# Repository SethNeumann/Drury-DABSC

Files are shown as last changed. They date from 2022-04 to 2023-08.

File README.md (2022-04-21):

# REPO NAME: Drury-DABSC
## License: Creative Commons Attribution-NonCommercial-ShareAlike

Dennis Drury designed the Dual ABS Controller (DABSC) as a simple solution for ABS.  
  
The Dual ABS Signal Controller provides a simple, no software, solution for the modeler looking for a prototypical Automatic Block Signaling (ABS) system.
This board provides signal control for two blocks of 3 aspect (Green - Yellow - Red) route signaling for two blocks.  
The Dual ABS Signal Controller can be used in either single track (1 segment for each signaled direction) or double track (Rule 251, Current of Traffic)
applications.

This is an excellent product for modular and sectional railroads as well as permanent applications.  We recommend our cpOD (screw terminal option) detector
for detection input. The Dual ABS Signal Controller is NOT MSS compatible.

This board is designed and supported by Dennis Drury, a former Southern Pacific Signal Maintainer and the design has given him good service for 30 years!
See Dennis' clinic from the 2017 PCR Convention on the development of this board on the www.modelrailroadcontrolsystems.com sitte under Simple Signaling 
and accessories

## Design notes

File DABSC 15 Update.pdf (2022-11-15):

# Dual ABS Controller V1.5 Update

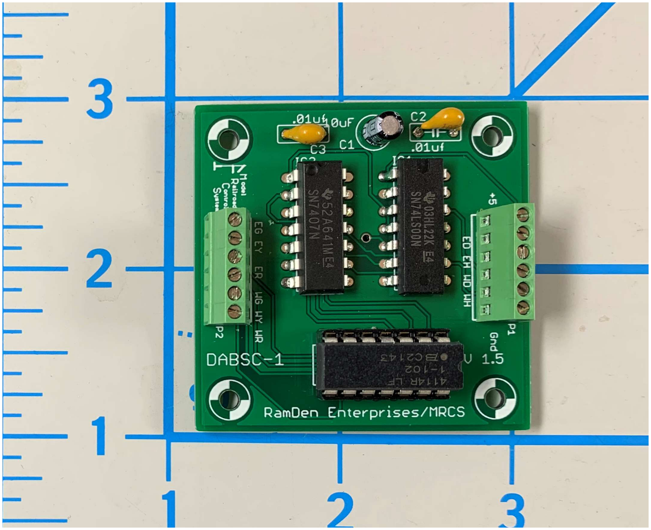
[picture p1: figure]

# Why did we do this update?

## - Changes to current limiting resistors

- Old design was hard to build for stock and test • Resistors values change based on type of signal and users’ color vision
- No easy way to test without soldering resistors in
- Solution: • All resistors on 0.300 grid (same as before) but in 14 pin DIP format • Uses either 14 pin “machined pin” DIP scket or 2 x 7 pin female socket headers
- Allows for use of 7 position DIP resistor networks (if all values the same) or user can insert individual resistors to suit their preferences and change easily.
- Other • Changed 10uF cap to radial (stands up to save space) from axial format • Changed .1 uF ceramic caps to 0.200 spacing to use inventory I had on hand

# Ooops

## - When I panelized the DABSC board, I neglected to check the CAD file for documentation layer, so the output legends were not printed in

the silk screen. This will be corrected in the next build.

Resistor Network*

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
output | input

EG
EY
ER
WG
WY
WR

Resistor network is Bournes 4114R-1-102LF for 1K which is my standard, but these are available in a wide variety of values, or bend 1/4W resistors to 0.300 and insert in socket

- +5 Volts
- ED – East Sensor Distant • EH – East Sensor Home
- WD - West Sensor Distant • WH – West Sensor Home
- GND - Ground
- EG – Eastward Signal Green
- EY – Eastward Signal Yellow
- ER – Eastward Signal Red
- WG - Westward Signal Green
- WY – Westward Signal Yellow
- WR - Westward Signal Red

# Photo

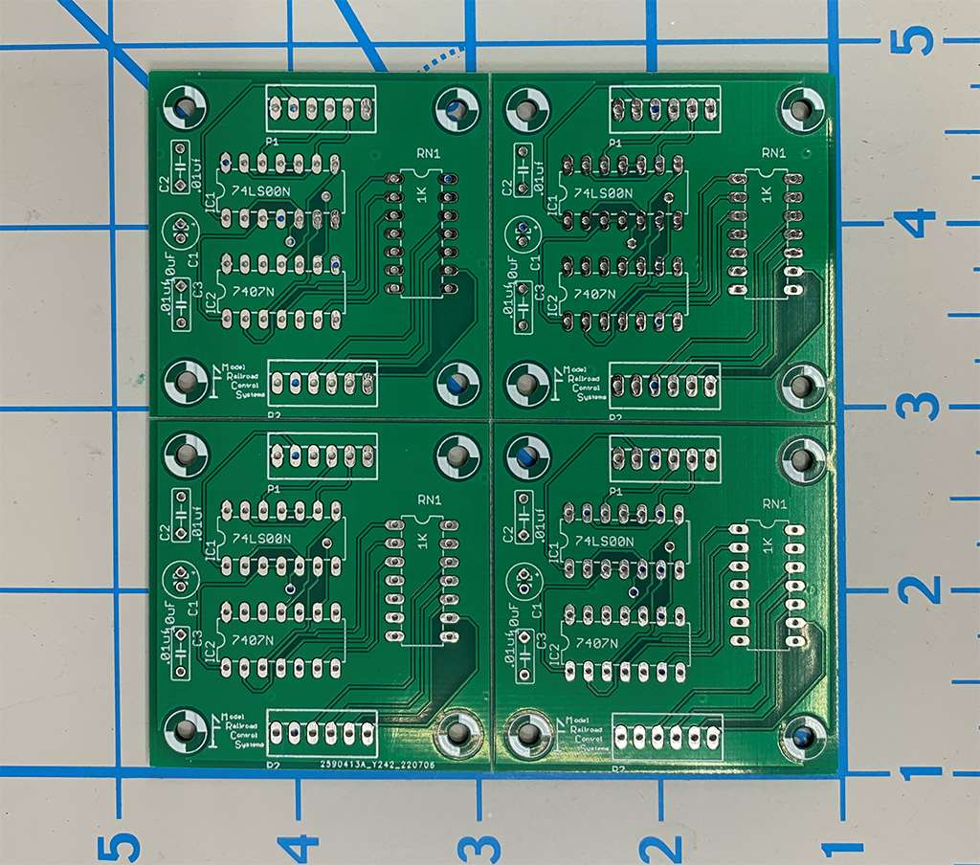
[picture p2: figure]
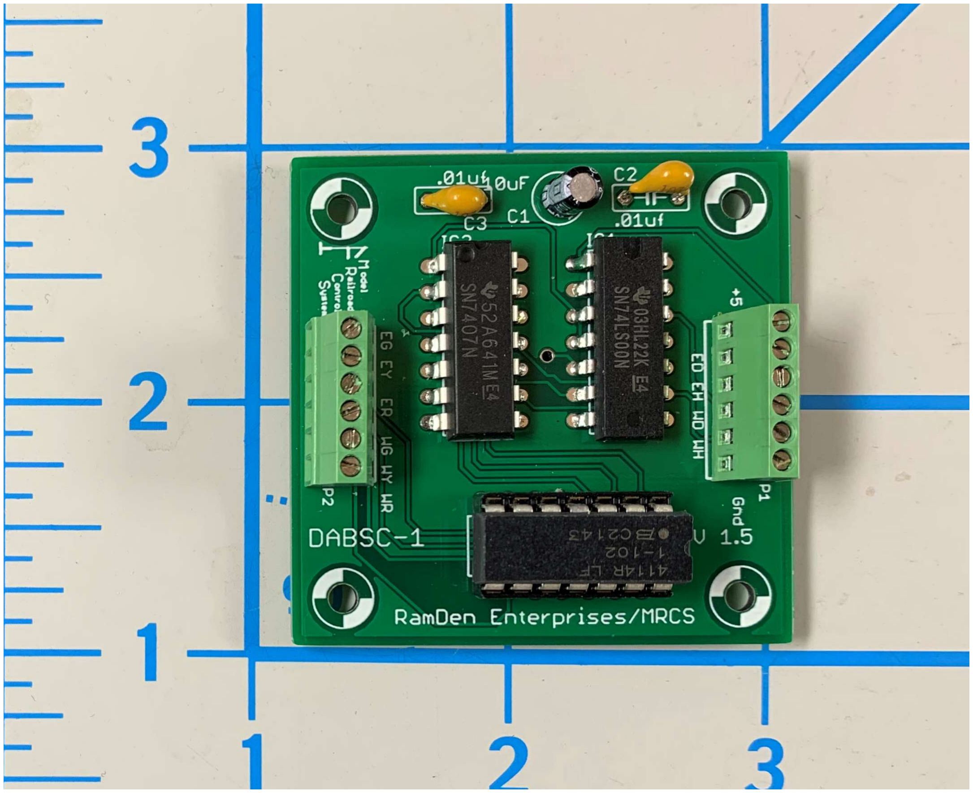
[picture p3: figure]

4 x Panel – no labels | Original Singlet – note labels

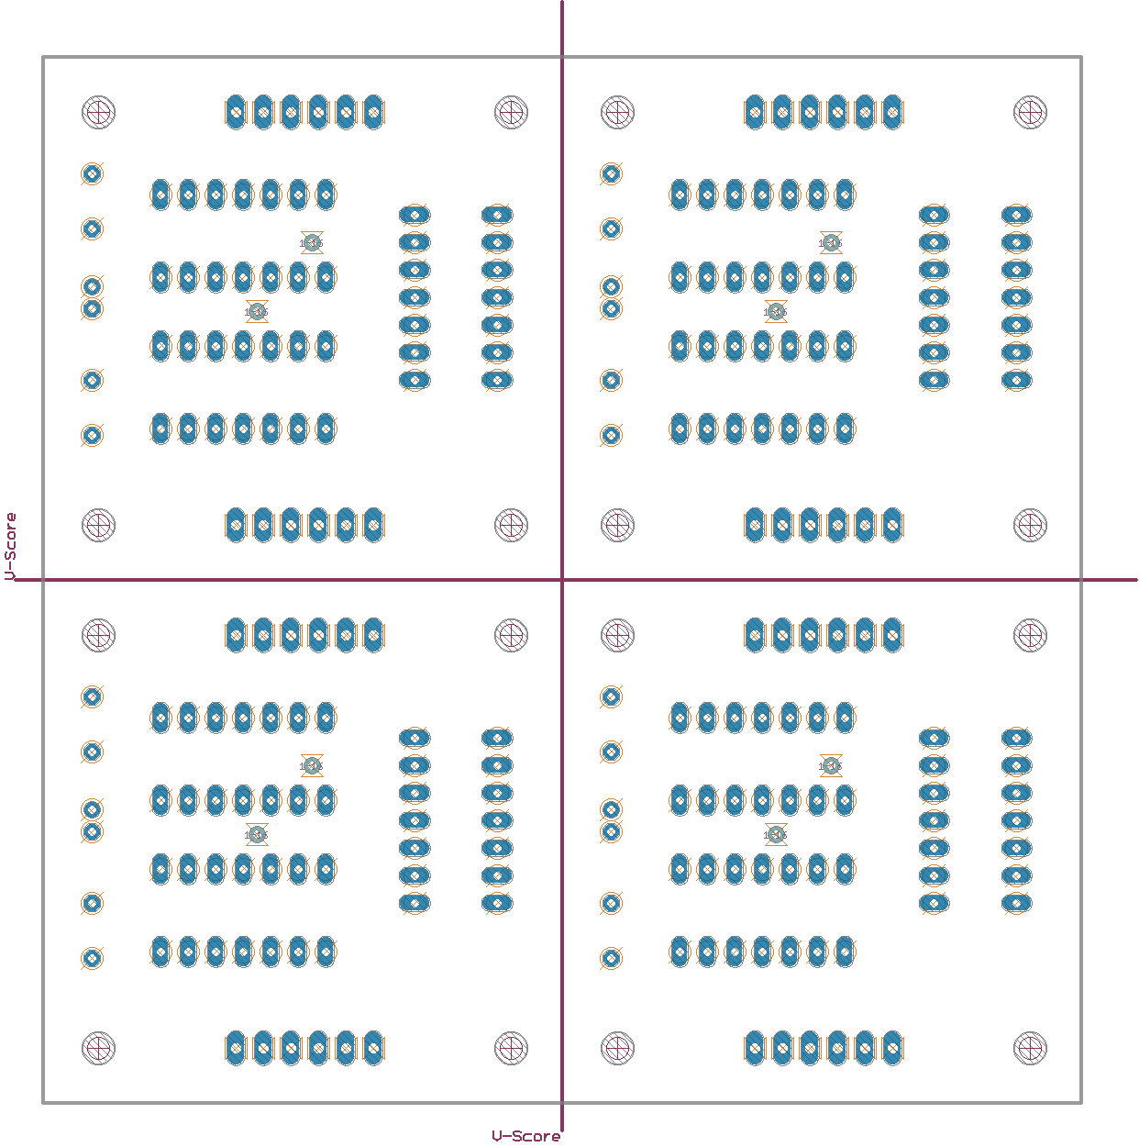
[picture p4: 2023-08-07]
Plocher 20221122/Drury-DABSC_array.bot.brd.png

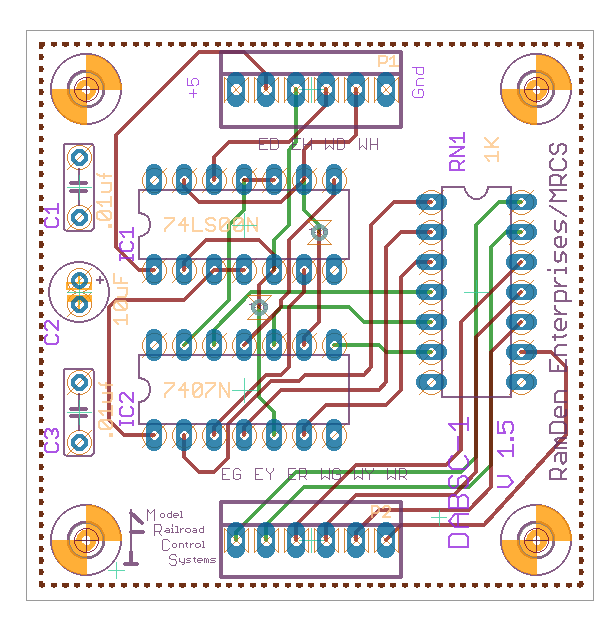
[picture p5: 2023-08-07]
Plocher 20221122/Drury-DABSC.brd.png

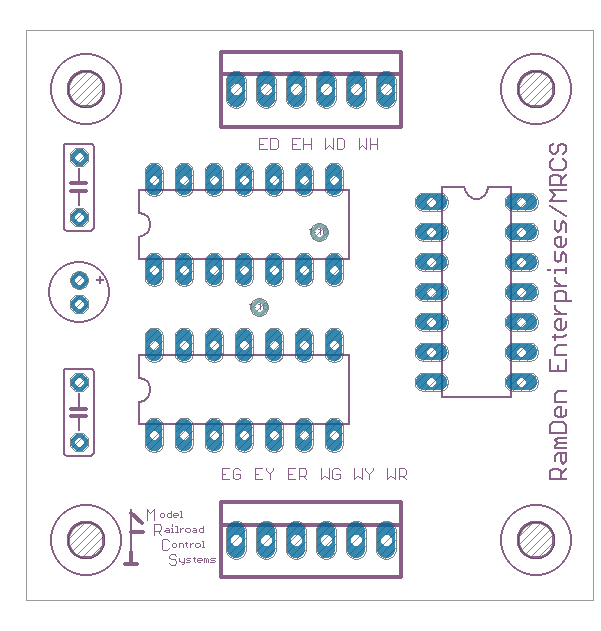
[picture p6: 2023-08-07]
Plocher 20221122/Drury-DABSC.top.brd.png

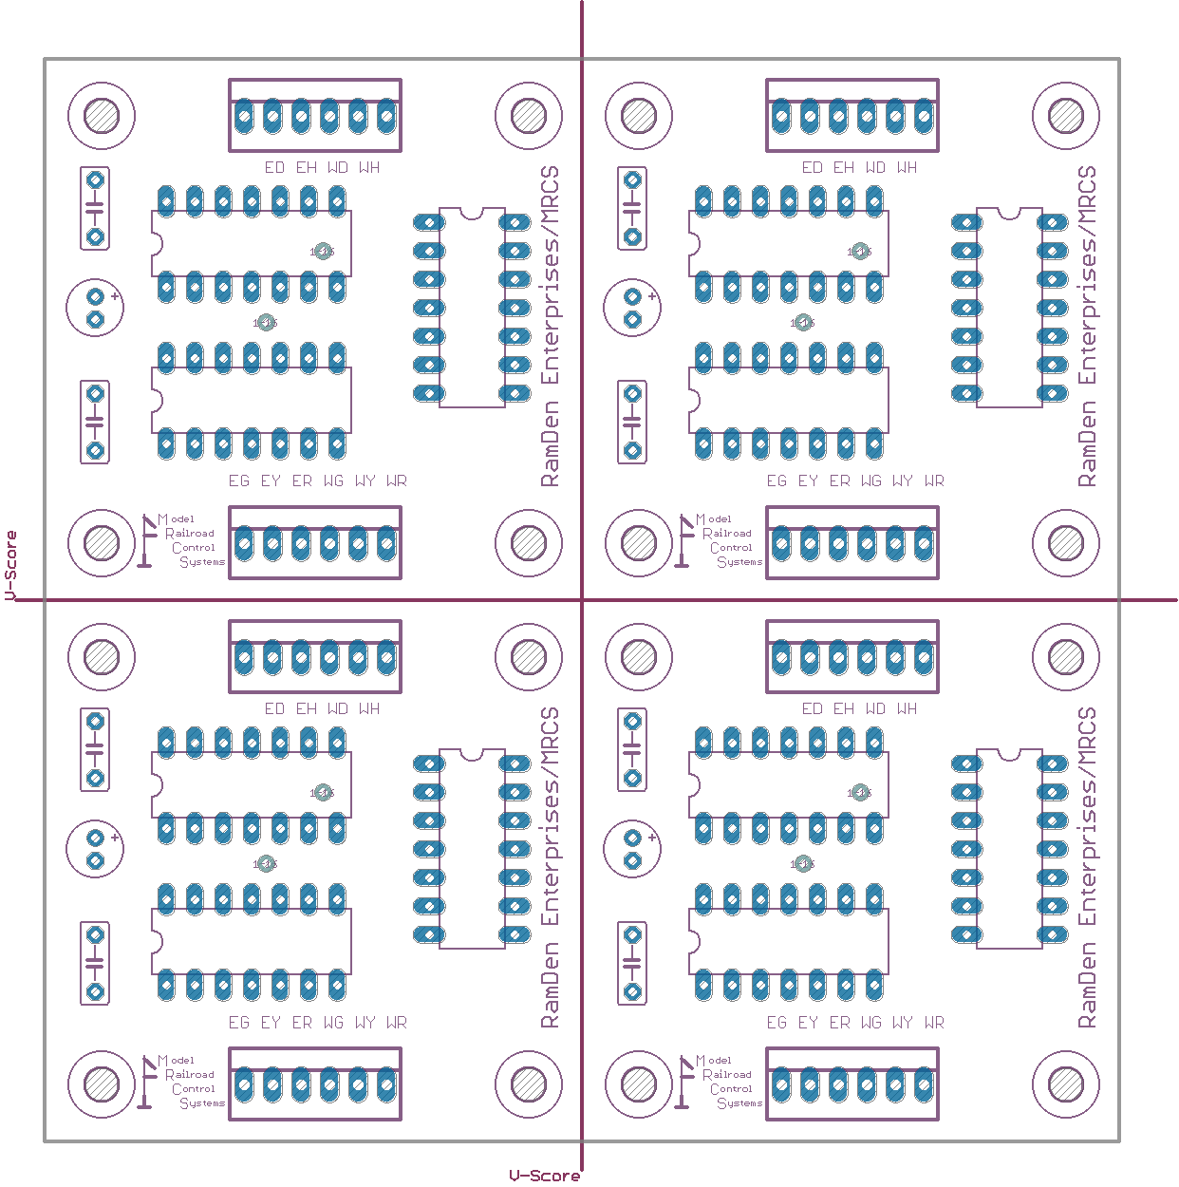
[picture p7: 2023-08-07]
Plocher 20221122/Drury-DABSC_array.top.brd.png

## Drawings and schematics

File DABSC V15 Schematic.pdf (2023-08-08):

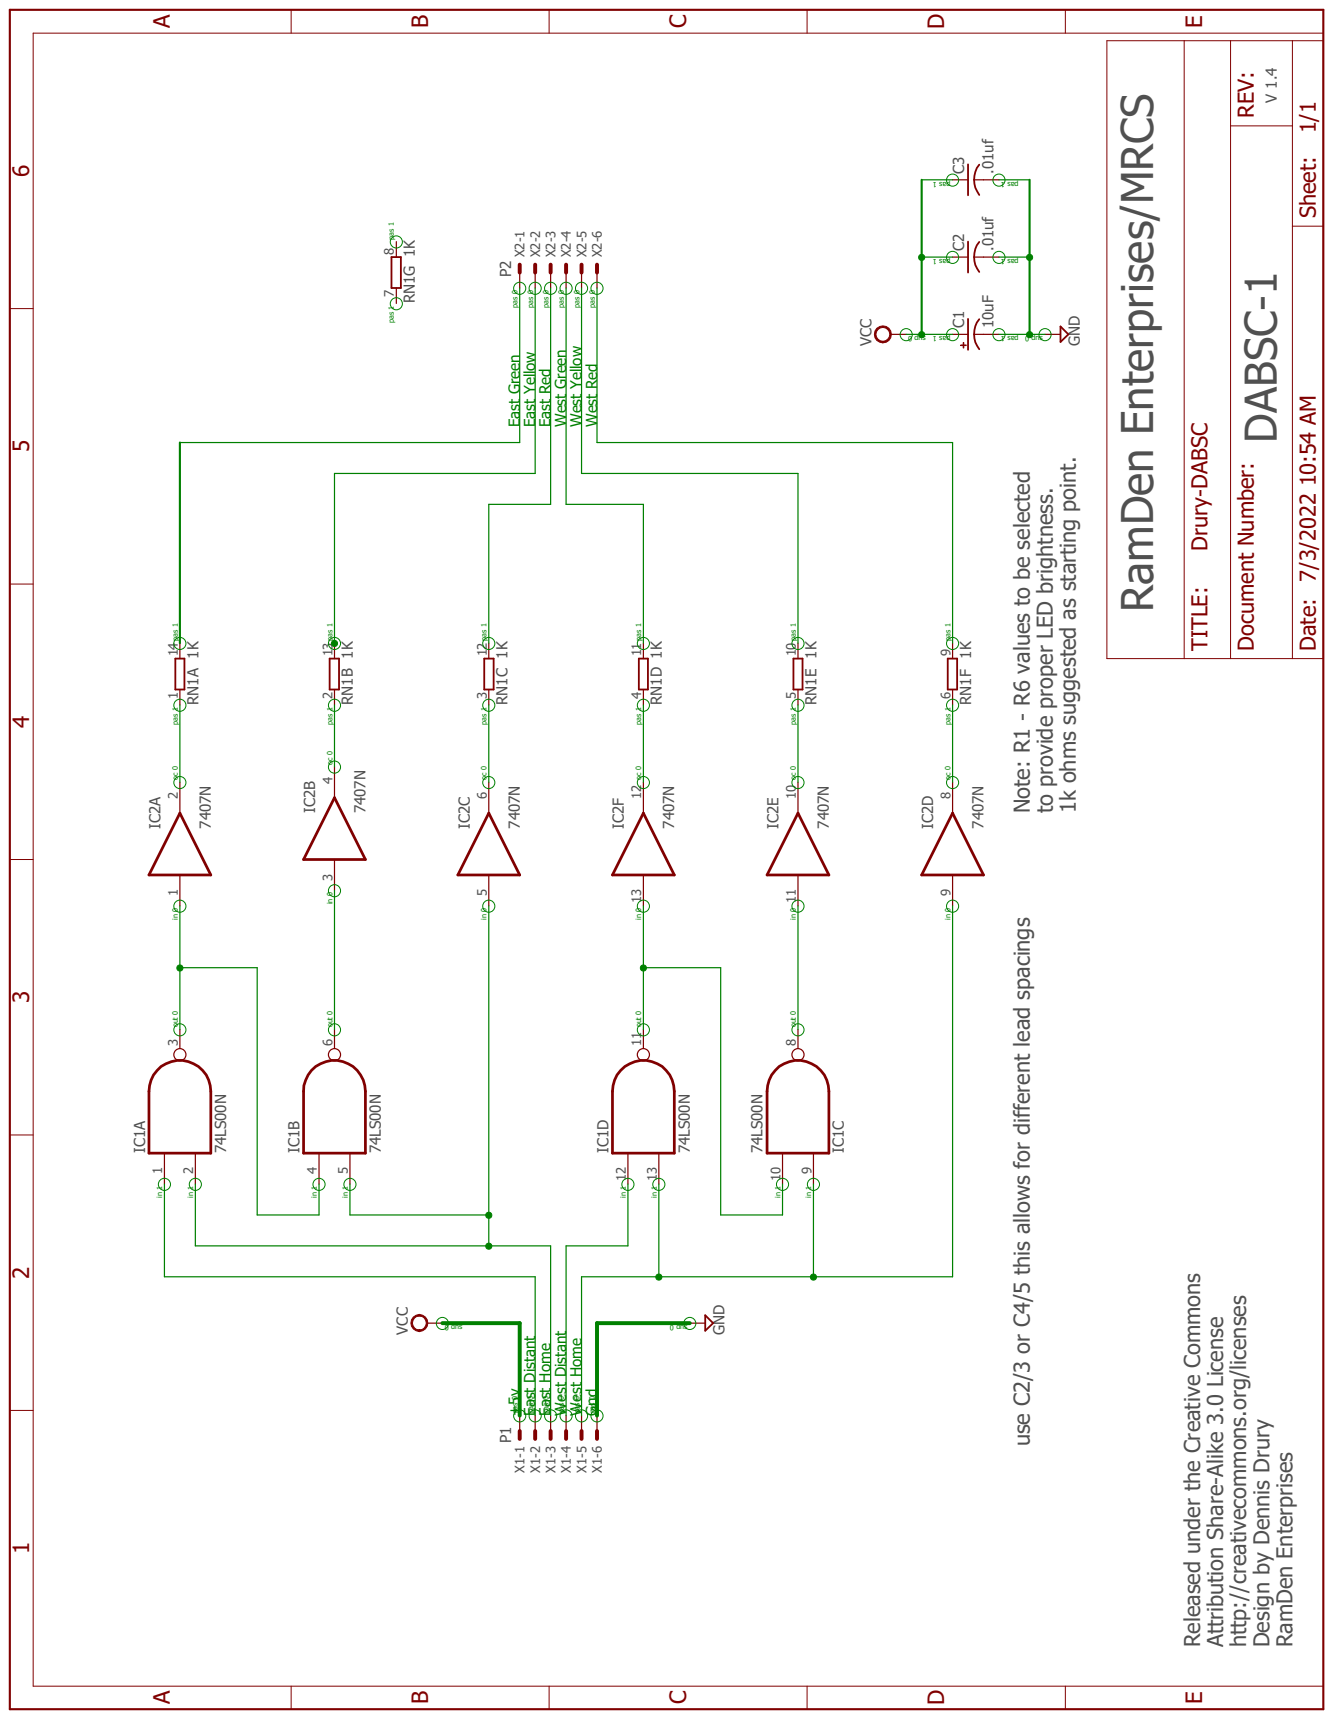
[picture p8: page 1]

RamDen Enterprises/MRCSV 1.4 DABSC-1 Released under the Creative Commons Attribution Share-Alike 3.0 License http://creativecommons.org/licenses Design by Dennis Drury RamDen Enterprises Note: R1 - R6 values to be selected to provide proper LED brightness. 1k ohms suggested as starting point. use C2/3 or C4/5 this allows for different lead spacings 74LS00N 74LS00N 74LS00N 74LS00N 7407N 7407N 7407N 7407N 7407N 7407N GND GND .01uf .01uf VCC VCC10uF P1 P2 1K1K1K1K1K1K 1K 12 3 IC1A 45 6 IC1B 910 8 IC1C 1213 11 IC1D 1 2 IC2A 3 4 IC2B 5 6 IC2C 9 8 IC2D 11 10 IC2E 13 12 IC2F C2 C3 C1 X1-1 X1-2 X1-3 X1-4 X1-5 X1-6 X2-1 X2-2 X2-3 X2-4 X2-5 X2-6 1 14 RN1A 2 13 RN1B 3 12 RN1C 4 11 RN1D 5 10 RN1E 6 9 RN1F 7 8 RN1G ABCDE ABCDE 1 2 3 4 5 6 Date: Sheet: REV: TITLE: Document Number: 7/3/2022 10:54 AM 1/1 Drury-DABSC in 1 in 1 out 0 in 1 in 1 out 0 in 1 in 1 out 0 in 1 in 1 out 0 in 0 oc 0 in 0 oc 0 in 0 oc 0 in 0 oc 0 in 0 oc 0 in 0 oc 0

sup 0 pas 1 pas 1 pas 1 pas 1

sup 0 pas 1 pas 1 pas 0 pas 0 pas 0 pas 0 pas 0 pas 0 pas 0 pas 0 pas 0 pas 0 pas 0 pas 0 pas 1 pas 1 pas 1 pas 1 pas 1 pas 1 pas 1 pas 1 pas 1 pas 1 pas 1 pas 1 pas 1 pas 1 East Distant East Home West Distant West Home East Green East Yellow East Red West Green West Yellow West Red +5v Gnd

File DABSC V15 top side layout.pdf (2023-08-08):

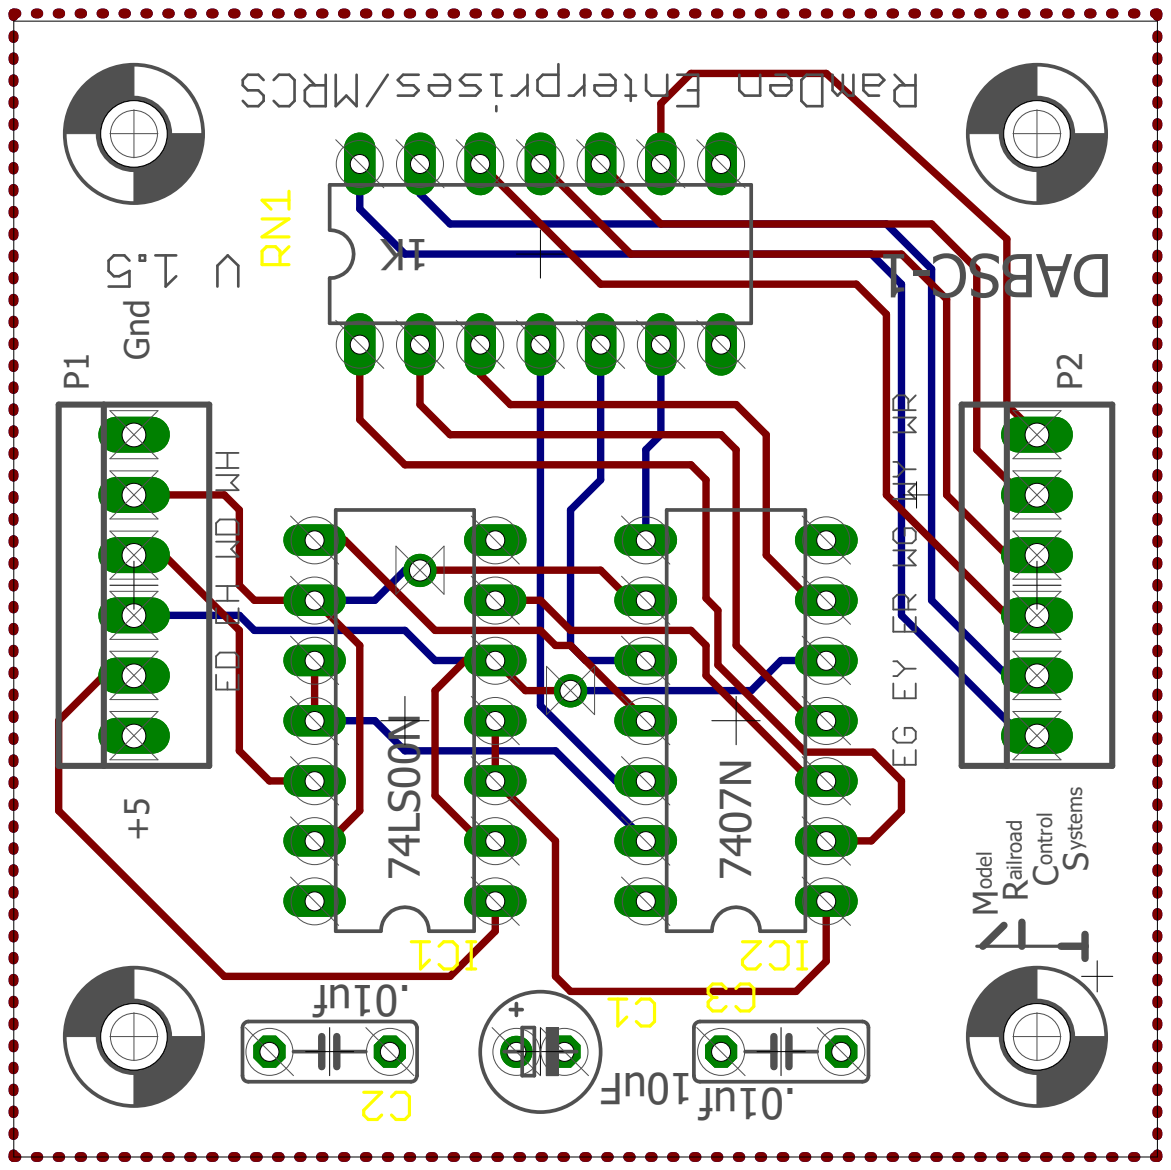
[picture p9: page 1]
DABSC-1 +5 Gnd

MRCSystems ontrol ailroad odel

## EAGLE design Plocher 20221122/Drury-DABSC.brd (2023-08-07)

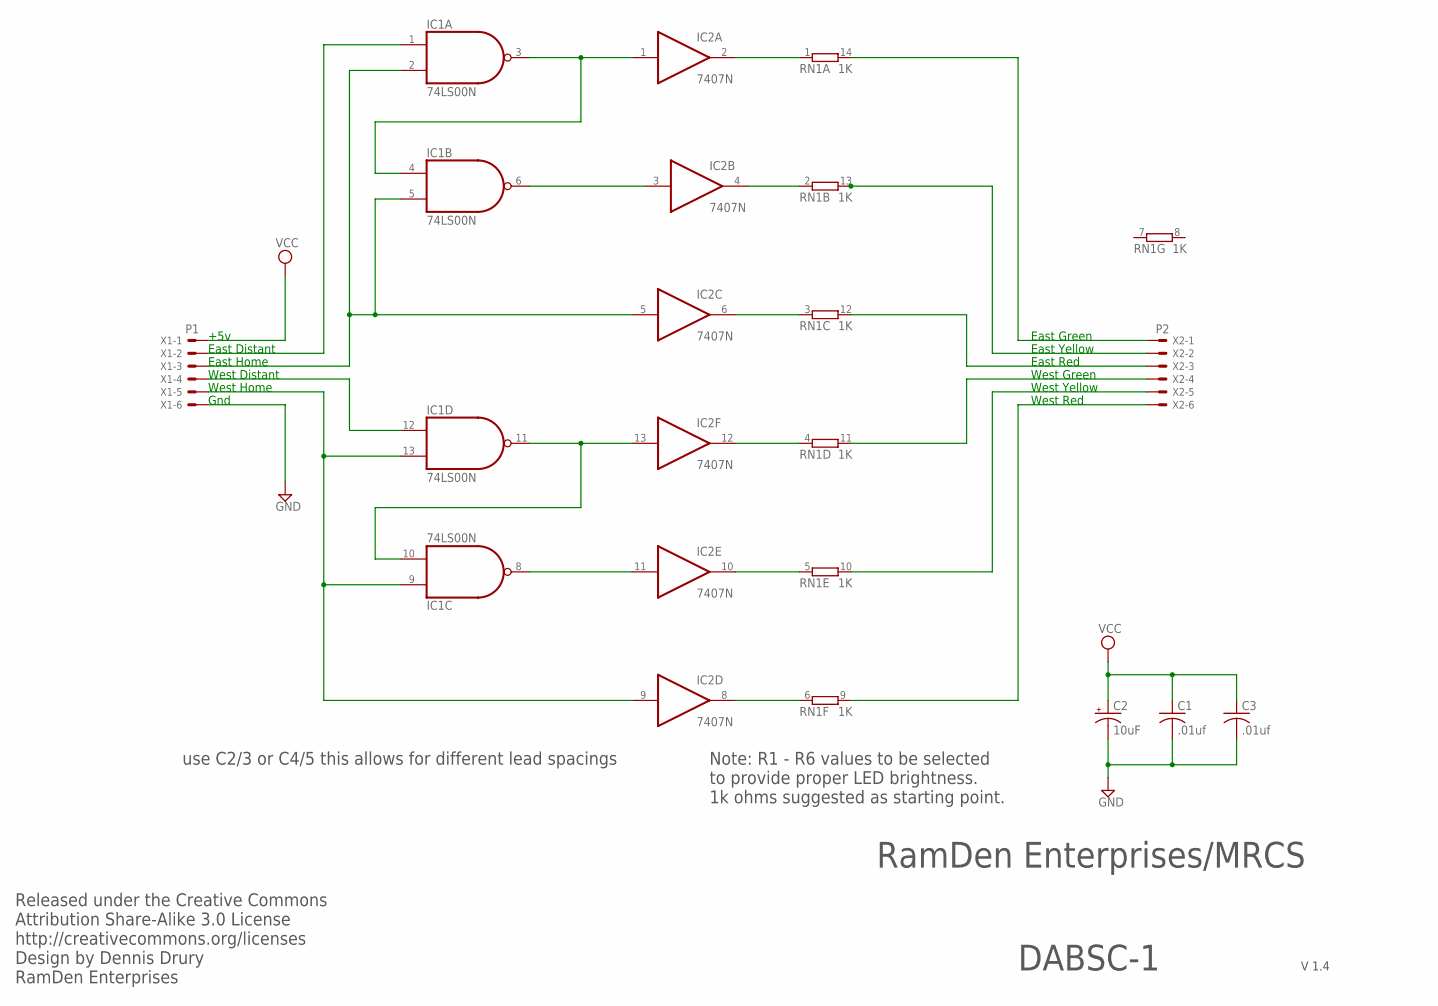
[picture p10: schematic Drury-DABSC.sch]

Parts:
C1, C3: .01uf; C050-025X075
C2: 10uF; E2-5
IC1: 74LS00N; DIL14
IC2: 7407N; DIL14
RN1: 1K; DIL14
X1: P1; 22-23-2061
X2: P2; 22-23-2061

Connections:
GND: C1.2, C2.-, C3.2, IC1.7 (GND), IC2.7 (GND), X1.6
unnamed: IC1.3 (O), IC1.4 (I0), IC2.1 (I)
unnamed: IC1.6 (O), IC2.3 (I)
unnamed: IC2.2 (O), RN1.1
unnamed: IC1.8 (O), IC2.11 (I)
unnamed: IC2.4 (O), RN1.2 (1)
unnamed: IC1.10 (I1), IC1.11 (O), IC2.13 (I)
unnamed: IC2.6 (O), RN1.3 (1)
unnamed: RN1.14 (2), X2.1
unnamed: RN1.13 (2), X2.2
unnamed: IC1.1 (I0), X1.2
unnamed: IC1.2 (I1), IC1.5 (I1), IC2.5 (I), X1.3
unnamed: RN1.12 (2), X2.3
unnamed: IC2.12 (O), RN1.4 (1)
unnamed: IC2.10 (O), RN1.5 (1)
unnamed: IC2.8 (O), RN1.6 (1)
unnamed: RN1.9 (2), X2.6
unnamed: RN1.10 (2), X2.5
unnamed: IC1.12 (I0), X1.4
unnamed: RN1.11 (2), X2.4
unnamed: IC1.9 (I0), IC1.13 (I1), IC2.9 (I), X1.5
VCC: C1.1, C2.+, C3.1, IC1.14 (VCC), IC2.14 (VCC), X1.1

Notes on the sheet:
RamDen Enterprises/MRCS
V 1.4
DABSC-1
East Distant
East Home
West Home
West Distant
East Green
East Yellow
East Red
West Green
West Yellow
West Red
Released under the Creative Commons Attribution Share-Alike 3.0 License http://creativecommons.org/licenses Design by Dennis Drury RamDen Enterprises
Note: R1 - R6 values to be selected to provide proper LED brightness. 1k ohms suggested as starting point.
+5v
Gnd
use C2/3 or C4/5 this allows for different lead spacings

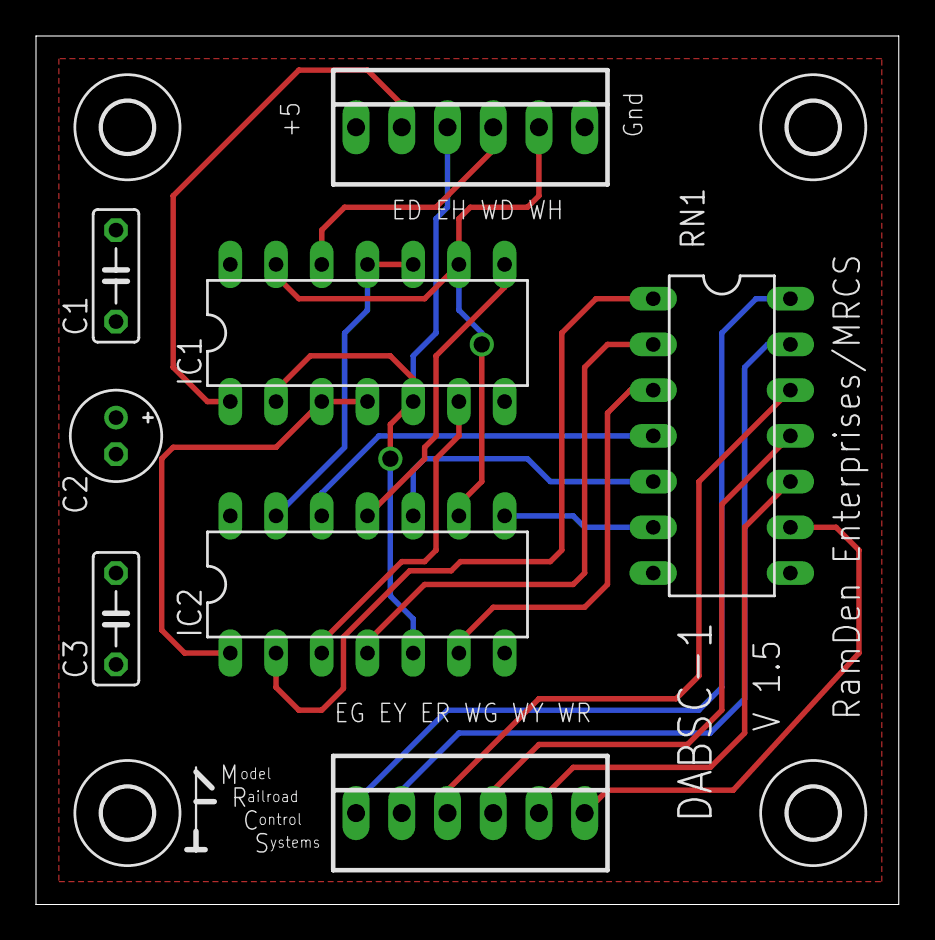
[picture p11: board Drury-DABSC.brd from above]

Board: 2 copper layers, 47.9 x 48.2 mm, 14 parts (0 on the bottom side), 22 nets.

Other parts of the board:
U$1, U$2, U$3, U$4: 2,8
U$5: MRCSLOGOTOP
U$6: CA-PROP65-BACK

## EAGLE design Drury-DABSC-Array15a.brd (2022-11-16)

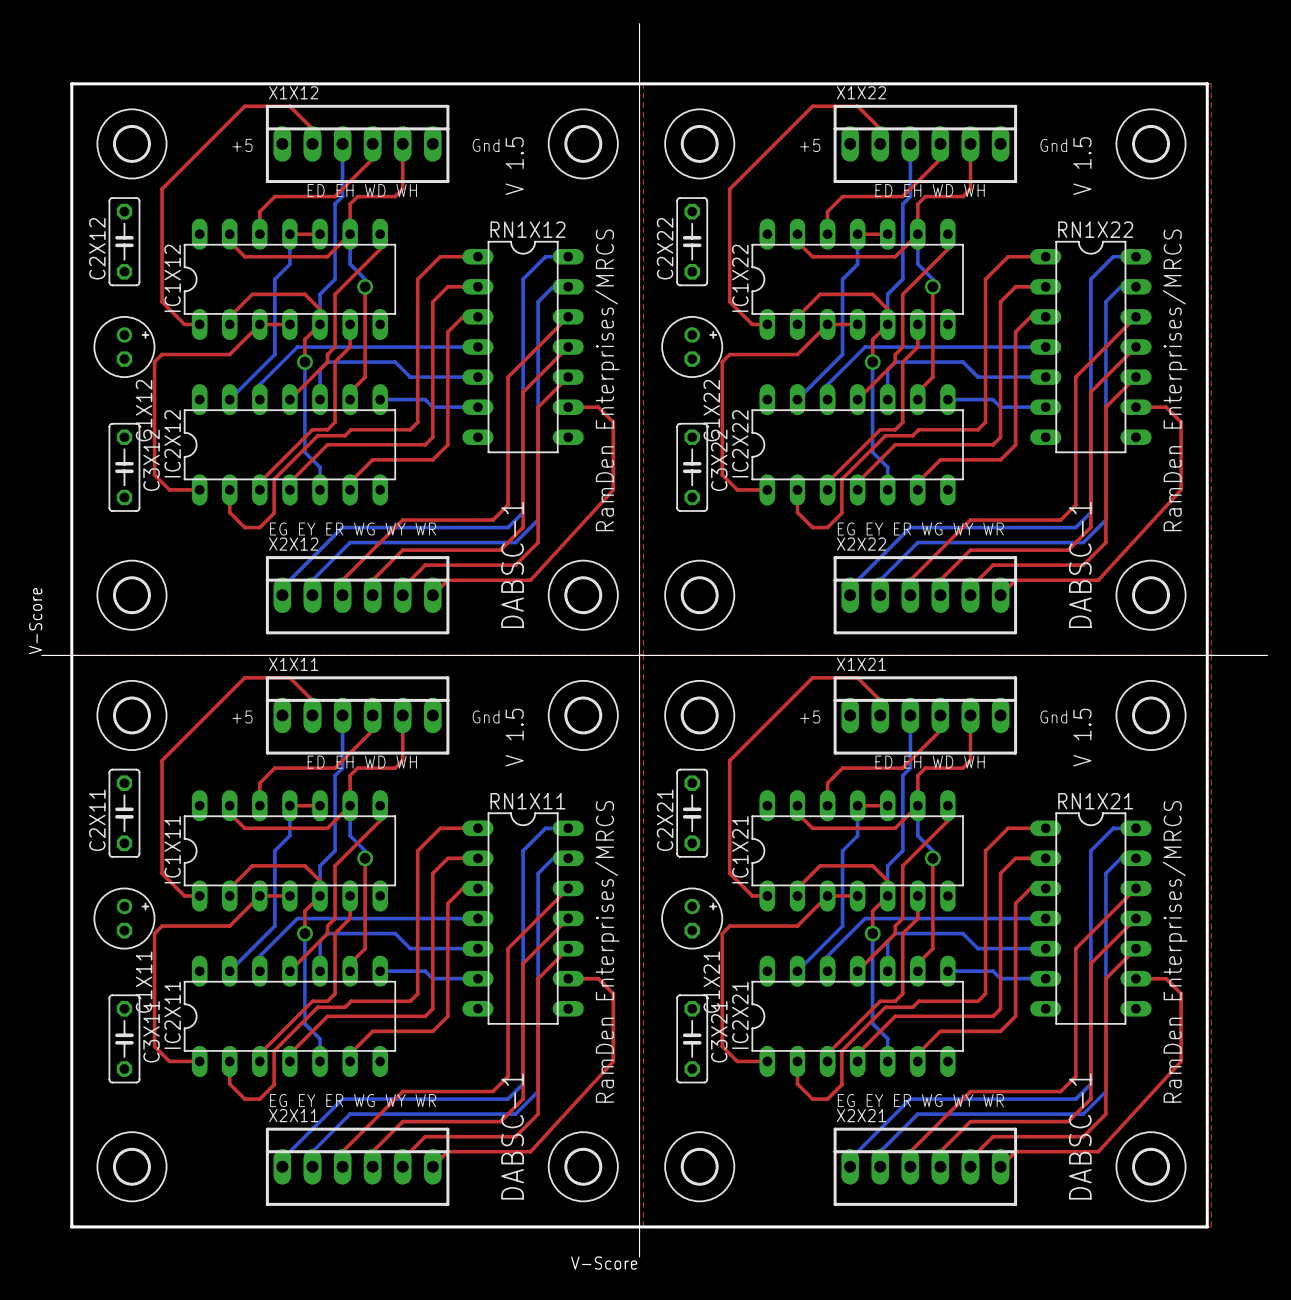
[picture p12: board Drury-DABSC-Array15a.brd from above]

Board: 2 copper layers, 103.5 x 104.1 mm, 56 parts (0 on the bottom side), 88 nets.

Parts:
C1X11, C1X12, C1X21, C1X22: 10uF; E2-5
C2X11, C2X12, C2X21, C2X22, C3X11, C3X12, C3X21, C3X22: .01uf; C050-025X075
IC1X11, IC1X12, IC1X21, IC1X22: 74LS00N; DIL14
IC2X11, IC2X12, IC2X21, IC2X22: 7407N; DIL14
RN1X11, RN1X12, RN1X21, RN1X22: 1K; DIL14
U$1X11, U$1X12, U$1X21, U$1X22, U$2X11, U$2X12, U$2X21, U$2X22, U$3X11, U$3X12, U$3X21, U$3X22, U$4X11, U$4X12, U$4X21, U$4X22: 2,8
U$5X11, U$5X12, U$5X21, U$5X22: MRCSLOGOTOP
U$6X11, U$6X12, U$6X21, U$6X22: CA-PROP65WARNING
X1X11, X1X12, X1X21, X1X22: P1; 22-23-2061
X2X11, X2X12, X2X21, X2X22: P2; 22-23-2061

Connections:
GNDX11: C1X11.-, C2X11.2, C3X11.2, IC1X11.7, IC2X11.7, X1X11.6
GNDX12: C1X12.-, C2X12.2, C3X12.2, IC1X12.7, IC2X12.7, X1X12.6
GNDX21: C1X21.-, C2X21.2, C3X21.2, IC1X21.7, IC2X21.7, X1X21.6
GNDX22: C1X22.-, C2X22.2, C3X22.2, IC1X22.7, IC2X22.7, X1X22.6
unnamed: IC1X11.3, IC1X11.4, IC2X11.1
unnamed: IC1X12.3, IC1X12.4, IC2X12.1
unnamed: IC1X21.3, IC1X21.4, IC2X21.1
unnamed: IC1X22.3, IC1X22.4, IC2X22.1
unnamed: IC1X11.6, IC2X11.3
unnamed: IC1X12.6, IC2X12.3
unnamed: IC1X21.6, IC2X21.3
unnamed: IC1X22.6, IC2X22.3
unnamed: IC2X11.2, RN1X11.1
unnamed: IC2X12.2, RN1X12.1
unnamed: IC2X21.2, RN1X21.1
unnamed: IC2X22.2, RN1X22.1
unnamed: IC1X11.8, IC2X11.11
unnamed: IC1X12.8, IC2X12.11
unnamed: IC1X21.8, IC2X21.11
unnamed: IC1X22.8, IC2X22.11
unnamed: IC2X11.4, RN1X11.2
unnamed: IC2X12.4, RN1X12.2
unnamed: IC2X21.4, RN1X21.2
unnamed: IC2X22.4, RN1X22.2
unnamed: IC1X11.10, IC1X11.11, IC2X11.13
unnamed: IC1X12.10, IC1X12.11, IC2X12.13
unnamed: IC1X21.10, IC1X21.11, IC2X21.13
unnamed: IC1X22.10, IC1X22.11, IC2X22.13
unnamed: IC2X11.6, RN1X11.3
unnamed: IC2X12.6, RN1X12.3
unnamed: IC2X21.6, RN1X21.3
unnamed: IC2X22.6, RN1X22.3
unnamed: RN1X11.14, X2X11.1
unnamed: RN1X12.14, X2X12.1
unnamed: RN1X21.14, X2X21.1
unnamed: RN1X22.14, X2X22.1
unnamed: RN1X11.13, X2X11.2
unnamed: RN1X12.13, X2X12.2
unnamed: RN1X21.13, X2X21.2
unnamed: RN1X22.13, X2X22.2
unnamed: IC1X11.1, X1X11.2
unnamed: IC1X12.1, X1X12.2
unnamed: IC1X21.1, X1X21.2
unnamed: IC1X22.1, X1X22.2
unnamed: IC1X11.2, IC1X11.5, IC2X11.5, X1X11.3
unnamed: IC1X12.2, IC1X12.5, IC2X12.5, X1X12.3
unnamed: IC1X21.2, IC1X21.5, IC2X21.5, X1X21.3
unnamed: IC1X22.2, IC1X22.5, IC2X22.5, X1X22.3
unnamed: RN1X11.12, X2X11.3
unnamed: RN1X12.12, X2X12.3
unnamed: RN1X21.12, X2X21.3
unnamed: RN1X22.12, X2X22.3
unnamed: IC2X11.12, RN1X11.4
unnamed: IC2X12.12, RN1X12.4
unnamed: IC2X21.12, RN1X21.4
unnamed: IC2X22.12, RN1X22.4
unnamed: IC2X11.10, RN1X11.5
unnamed: IC2X12.10, RN1X12.5
unnamed: IC2X21.10, RN1X21.5
unnamed: IC2X22.10, RN1X22.5
unnamed: IC2X11.8, RN1X11.6
unnamed: IC2X12.8, RN1X12.6
unnamed: IC2X21.8, RN1X21.6
unnamed: IC2X22.8, RN1X22.6
unnamed: RN1X11.9, X2X11.6
unnamed: RN1X12.9, X2X12.6
unnamed: RN1X21.9, X2X21.6
unnamed: RN1X22.9, X2X22.6
unnamed: RN1X11.10, X2X11.5
unnamed: RN1X12.10, X2X12.5
unnamed: RN1X21.10, X2X21.5
unnamed: RN1X22.10, X2X22.5
unnamed: IC1X11.12, X1X11.4
unnamed: IC1X12.12, X1X12.4
unnamed: IC1X21.12, X1X21.4
unnamed: IC1X22.12, X1X22.4
unnamed: RN1X11.11, X2X11.4
unnamed: RN1X12.11, X2X12.4
unnamed: RN1X21.11, X2X21.4
unnamed: RN1X22.11, X2X22.4
unnamed: IC1X11.9, IC1X11.13, IC2X11.9, X1X11.5
unnamed: IC1X12.9, IC1X12.13, IC2X12.9, X1X12.5
unnamed: IC1X21.9, IC1X21.13, IC2X21.9, X1X21.5
unnamed: IC1X22.9, IC1X22.13, IC2X22.9, X1X22.5
VCCX11: C1X11.+, C2X11.1, C3X11.1, IC1X11.14, IC2X11.14, X1X11.1
VCCX12: C1X12.+, C2X12.1, C3X12.1, IC1X12.14, IC2X12.14, X1X12.1
VCCX21: C1X21.+, C2X21.1, C3X21.1, IC1X21.14, IC2X21.14, X1X21.1
VCCX22: C1X22.+, C2X22.1, C3X22.1, IC1X22.14, IC2X22.14, X1X22.1

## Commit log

2022-04-21 imported Dennis's original file as modified by John Plocher
    [Drury-DABSC.brd, Drury-DABSC.sch, EagleTemplate-new.brd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]
2022-05-07 cleanup of files, labels
    minor fixes for new rev
    [Drury-DABSC.GBL, Drury-DABSC.GBO, Drury-DABSC.GBS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]
2022-07-05 changes to support making a panel
    revised board (resistor array, pads for different cap sizes)
    [Drury-DABSC - Copy.brd, Drury-DABSC-Array.brd, Drury-DABSC.sch]
2022-11-16 changes to labels on terminal blocks
    Changes to labels on terminal blocks. Panelizer not picking them up, they were on Tnames, now on tplace.
    [Drury-DABSC-Array15a.brd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]
2023-08-07 latest version with resistor pack
    Changed to resistor pack to reduce stuffing labor. Use of machined pin socket allows user to insert 1/4W resistors if desired or pick a Bournes 4114 that meets your requirements.
    [Drury-DABSC.brd, Drury-DABSC.sch]
2023-08-08 updated pdf views of V15
    Version 1.5 uses 14 pin DIP for Bournes 4114 style resistor packs
